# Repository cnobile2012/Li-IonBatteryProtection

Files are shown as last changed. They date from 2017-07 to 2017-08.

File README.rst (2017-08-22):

*************************
Li-Ion Battery Protection
*************************
The MIT License (MIT)

This is an electronics project to help protect Li-Ion batteries and the
circuits they are used in. The circuit will work with two to four cells and
protects the battery at the cell level. Any one cell that goes below the
recomended level will cause the entire curcuit to shut down.

=======
LTspice
=======

Spice files for testing the circuit virtually.

Truth Table One: Battery Voltage Normal

+-------+-------+-------+-------+-------+
| U1/U3 | Q1/Q2 | U2/U4 |  Q3   |  Q4   |
+=======+=======+=======+=======+=======+
|  HI   |  LOW  |  LOW  |  HI   |  LOW  |
+-------+-------+-------+-------+-------+
|  N/A  |  ON   |  ON   |  OFF  |  ON   |
+-------+-------+-------+-------+-------+

Truth Table Two: Battery Voltage Below Normal

+-------+-------+-------+-------+-------+
| U1/U3 | Q1/Q2 | U2/U4 |  Q3   |  Q4   |
+=======+=======+=======+=======+=======+
|  LOW  |  HI   |  HI   |  LOW  |  HI   |
+-------+-------+-------+-------+-------+
|  N/A  |  OFF  |  OFF  |  ON   |  OFF  |
+-------+-------+-------+-------+-------+

=====
KiCAD
=====

KiCAD files of the schematic and PCB.

Feel free to contact me at: carl dot nobile at gmail.com

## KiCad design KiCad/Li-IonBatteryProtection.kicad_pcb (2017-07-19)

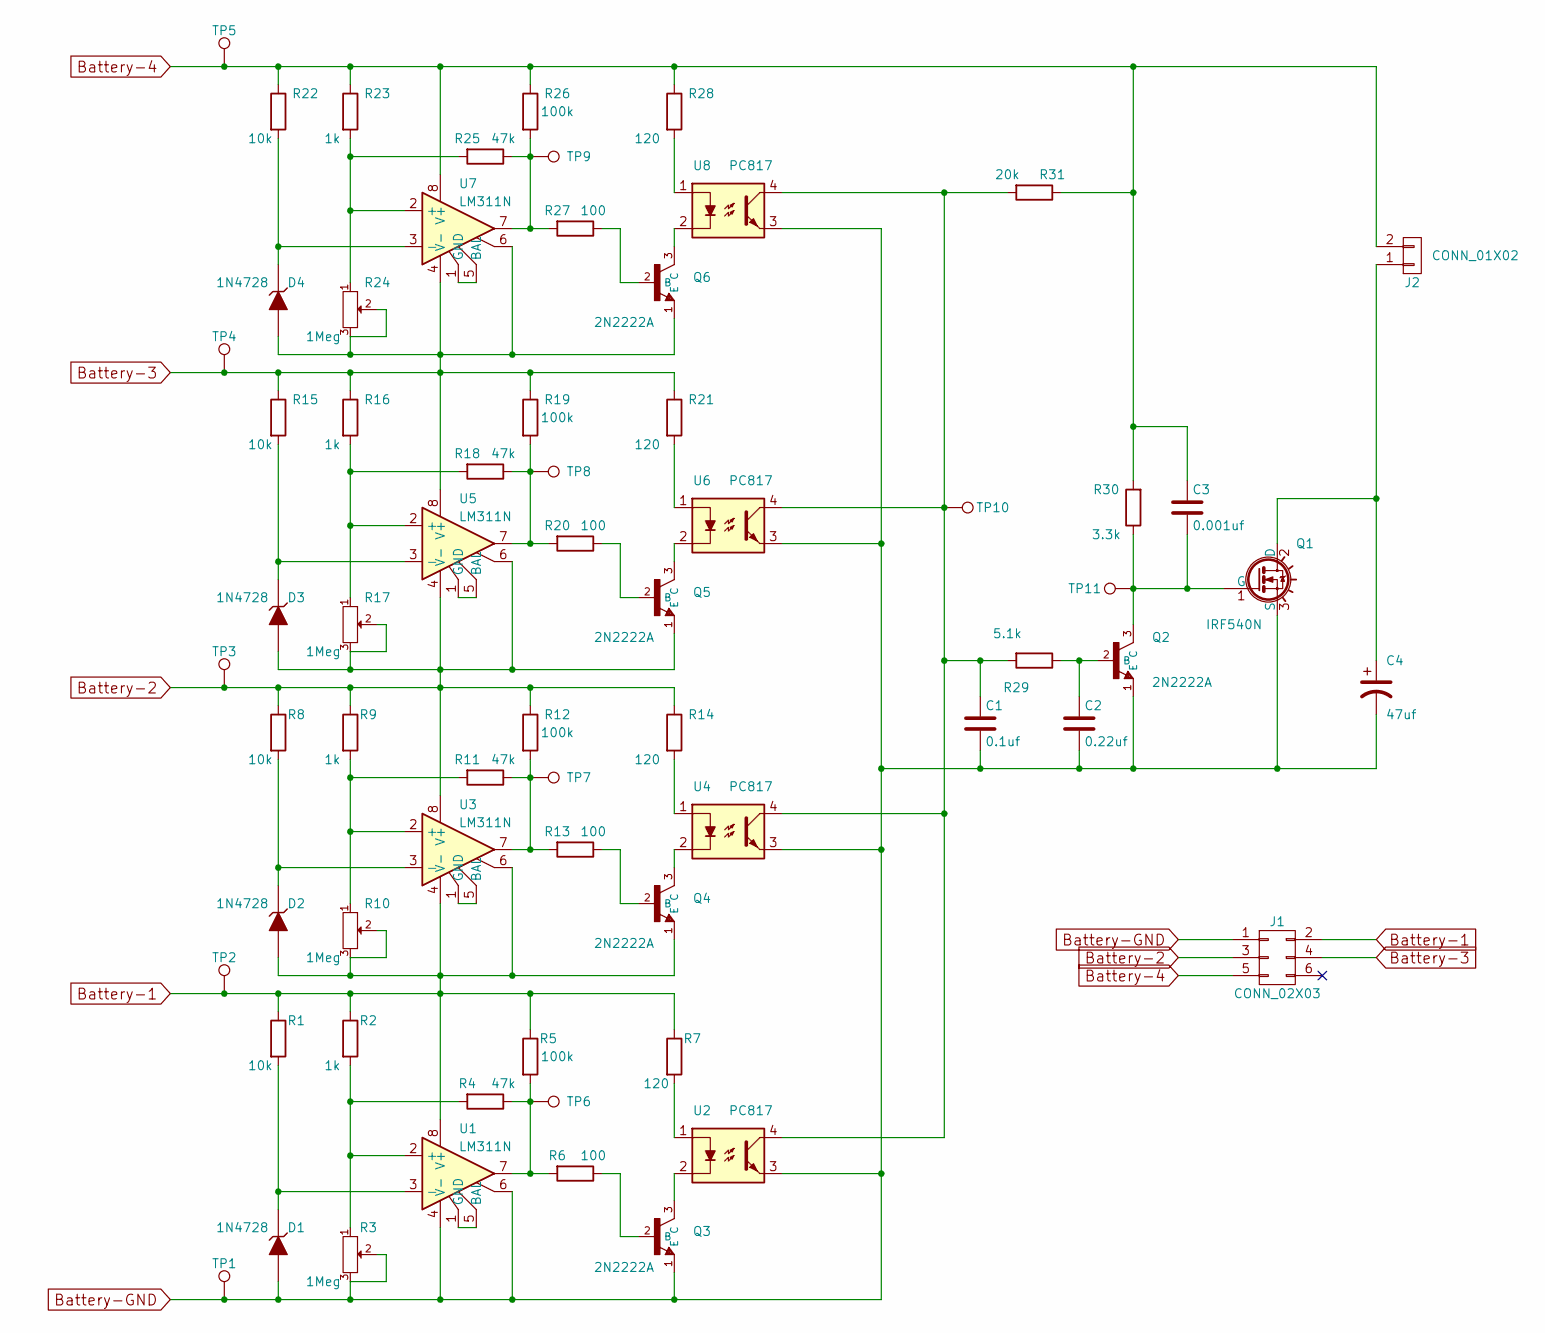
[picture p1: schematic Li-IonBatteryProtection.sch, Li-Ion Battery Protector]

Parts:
C1: 0.1uf; C_Rect_L4_W2.5_P2.5
C2: 0.22uf; C_Rect_L7_W2_P5
C3: 0.001uf; C_Rect_L7_W2_P5
C4: 47uf; C_Radial_D5_L11_P2.5
D1, D2, D3, D4: 1N4728; Diode_DO-41_SOD81_Horizontal_RM10
J1: CONN_02X03; Pin_Header_Straight_2x03
J2: CONN_01X02; TerminalBlock_Pheonix_MKDS1.5-2pol
Q1: IRF540N; TO-220_Neutral123_Horizontal
Q2, Q3, Q4, Q5, Q6: 2N2222A; TO-18_3Pin
R1, R8, R15, R22: 10k; Resistor_Horizontal_RM10mm
R2, R9, R16, R23: 1k; Resistor_Horizontal_RM10mm
R3, R10, R17, R24: 1Meg; Potentiometer_Bourns_3296Y_3-8Zoll_Angular_ScrewUp
R4, R11, R18, R25: 47k; Resistor_Horizontal_RM10mm
R5, R12, R19, R26: 100k; Resistor_Horizontal_RM10mm
R6, R13, R20, R27: 100; Resistor_Horizontal_RM10mm
R7, R14, R21, R28: 120; Resistor_Horizontal_RM10mm
R29: 5.1k; Resistor_Horizontal_RM10mm
R30: 3.3k; Resistor_Horizontal_RM10mm
R31: 20k; Resistor_Horizontal_RM10mm
TP1, TP2, TP3, TP4, TP5, TP6, TP7, TP8, TP9, TP10, TP11: TEST_1P; Measurement_Point_Round-TH_Small
U1, U3, U5, U7: LM311N; DIP-8_W7.62mm
U2, U4, U6, U8: PC817; DIP-4_W7.62mm

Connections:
Battery-1: D2.2 (A), J1.2, Q4.1 (E), R1.1, R2.1, R5.1, R7.1, R10.2, R10.3, TP2.1, U1.8 (V+), U3.4 (V-), U3.6
Battery-2: D3.2 (A), J1.3, Q5.1 (E), R8.1, R9.1, R12.1, R14.1, R17.2, R17.3, TP3.1, U3.8 (V+), U5.4 (V-), U5.6
Battery-3: D4.2 (A), J1.4, Q6.1 (E), R15.1, R16.1, R19.1, R21.1, R24.2, R24.3, TP4.1, U5.8 (V+), U7.4 (V-), U7.6
Battery-4: C3.1, J1.5, J2.2, R22.1, R23.1, R26.1, R28.1, R30.2, R31.1, TP5.1, U7.8 (V+)
Battery-GND: C1.2, C2.2, C4.2, D1.2 (A), J1.1, Q1.3 (S), Q2.1 (E), Q3.1 (E), R3.2, R3.3, TP1.1, U1.4 (V-), U1.6, U2.3, U4.3, U6.3, U8.3
unnamed: C1.1, R29.2, R31.2, TP10.1, U2.4, U4.4, U6.4, U8.4
unnamed: C2.1, Q2.2 (B), R29.1
unnamed: C3.2, Q1.1 (G), Q2.3 (C), R30.1, TP11.1
unnamed: C4.1, J2.1, Q1.2 (D)
unnamed: D1.1 (K), R1.2, U1.3 (-)
unnamed: D2.1 (K), R8.2, U3.3 (-)
unnamed: D3.1 (K), R15.2, U5.3 (-)
unnamed: D4.1 (K), R22.2, U7.3 (-)
unnamed: Q3.2 (B), R6.1
unnamed: Q3.3 (C), U2.2
unnamed: Q4.2 (B), R13.1
unnamed: Q4.3 (C), U4.2
unnamed: Q5.2 (B), R20.1
unnamed: Q5.3 (C), U6.2
unnamed: Q6.2 (B), R27.1
unnamed: Q6.3 (C), U8.2
unnamed: R2.2, R3.1, R4.2, U1.2 (+)
unnamed: R4.1, R5.2, R6.2, TP6.1, U1.7
unnamed: R7.2, U2.1
unnamed: R9.2, R10.1, R11.2, U3.2 (+)
unnamed: R11.1, R12.2, R13.2, TP7.1, U3.7
unnamed: R14.2, U4.1
unnamed: R16.2, R17.1, R18.2, U5.2 (+)
unnamed: R18.1, R19.2, R20.2, TP8.1, U5.7
unnamed: R21.2, U6.1
unnamed: R23.2, R24.1, R25.2, U7.2 (+)
unnamed: R25.1, R26.2, R27.2, TP9.1, U7.7
unnamed: R28.2, U8.1
unnamed: U1.1 (GND), U1.5 (BAL)
unnamed: U3.1 (GND), U3.5 (BAL)
unnamed: U5.1 (GND), U5.5 (BAL)
unnamed: U7.1 (GND), U7.5 (BAL)

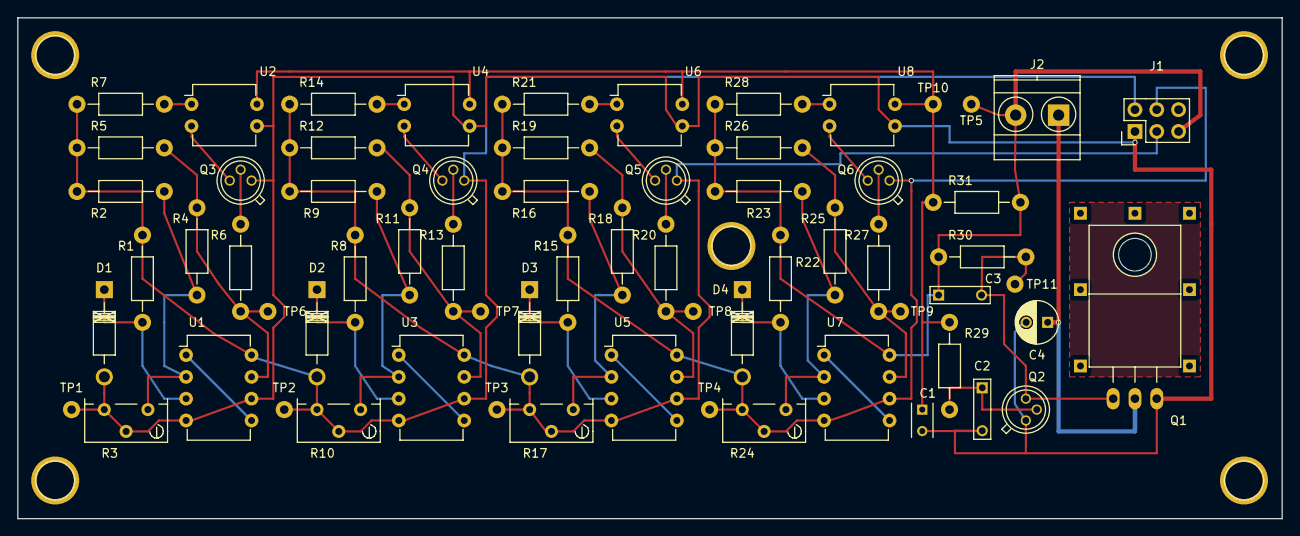
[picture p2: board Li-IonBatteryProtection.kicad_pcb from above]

Board: 2 copper layers, 147.2 x 58.3 mm, 69 parts (0 on the bottom side), 37 nets.

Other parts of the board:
W5, W7, W8: TEST_1P; Measurement_Point_Round-TH_Big

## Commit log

2017-06-23 Initial commit.
    [Li-IonBatteryProtection.kicad_pcb, Li-IonBatteryProtection.sch]
2017-06-25 Net wiring on PCB is done.
    [Li-IonBatteryProtection.kicad_pcb]
2017-06-26 Updated the PDB layout.
    [Li-IonBatteryProtection.kicad_pcb]
2017-06-27 Updated the TO-220 footprint. Started fill zones.
    [Li-IonBatteryProtection.kicad_pcb, Li-IonBatteryProtection.sch]
2017-06-28 Updated to the PCB.
    [Li-IonBatteryProtection.kicad_pcb]
2017-07-01 Hopefully finished the PCB.
    [Li-IonBatteryProtection.kicad_pcb]
2017-07-01 Added test points to the schematic.
    [Li-IonBatteryProtection.kicad_pcb, Li-IonBatteryProtection.sch]
2017-07-01 Updated the source files.
    [Li-IonBatteryProtection.kicad_pcb, Li-IonBatteryProtection.sch]
2017-07-01 Added gerber files.
    [Li-IonBatteryProtection-B.Cu.gbr, Li-IonBatteryProtection-B.Mask.gbr, Li-IonBatteryProtection-Edge.Cuts.gbr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]
2017-07-02 Updated the gerber files.
    [Li-IonBatteryProtection.kicad_pcb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]
2017-07-19 Moved J1 to give more distance between the shroud and the mounting hole.
    [Li-IonBatteryProtection.kicad_pcb]
2017-08-25 Added the remaining two battery circuits.
2017-10-07 Added diodes to prevent reverse biasing of the comparitors.
